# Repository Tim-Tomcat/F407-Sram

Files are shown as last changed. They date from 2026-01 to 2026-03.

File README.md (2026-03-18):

# F407-Sram
## Tổng quan dự án


  - Sơ đồ khối kết nối
  - Mục tiêu thiết kế:
    - Mạch debug STM, yêu cầu thiết lập trở kháng 90 Ohm đối với cổng USB.
    - Mạch USB <-> UART, giao tiếp với STM32.
    - Mạch gắn thẻ SD (sai footprint, không có linh kiện khớp).
    - Kết nối STM32F407ZGT6 với Sram 4Mbit thông qua bus FSMC.
      - Thiết lập trở kháng bus FSMC có giá trị 50 Ohm.
      - Kiểm soát length matching nhỏ nhất có thể (±2mm<).
      - Thêm điện trở nối tiếp để giảm over/undershoot và giảm méo tín hiệu. 
    - Kết nối với IC Ethernet DP83848 thông qua bus RMII (Thất bại).
      - Thiết lập trở kháng cho cổng ETH có giá trị 100 Ohm.
<br/>


Hình: Kiểm soát length matching(±2mm<)



Cách kết nối IC K6R4008V1D:
| Pin Name | Pin Function |
|---|---|
| A0 - A18 | Address Inputs |
| WE | Write Enable |
| CS | Chip Select |
| OE | Output Enable |
| I/O1 ~ I/O8  | Data Inputs/Outputs|

  - Được điều khiển bởi các tín hiệu: CS (Chip Select), WE (Write Enable), OE (Output Enable).
  - I/O1–I/O8 tạo thành bus dữ liệu song song 8 bit, hai chiều (bidirectional), dùng cho cả đọc và ghi SRAM tùy theo trạng thái điều khiển.
  - A0–A18 là các đường địa chỉ (19 bit), cho phép truy cập 2¹⁹ = 524,288 địa chỉ, tương ứng dung lượng 4 Mbit (512 KB).

<br/>




Hình: Mạch thi công thực tế
<br/>



<br/>



<br/>



<br/>



## Thử nghiệm đọc ghi Sram

Hình: FMC memory banks (RM0090, Figure 457)

  - Vùng địa chỉ của FMC được chia thành nhiều bank, trong đó Bank 1 (0x6000_0000 → 0x6FFF_FFFF) hỗ trợ các loại bộ nhớ như NOR, PSRAM và SRAM. Đây là vùng được sử dụng để ánh xạ SRAM ngoài trong thí nghiệm.
  - Sử dụng thư viện HAL, thử bằng phương pháp ghi và đọc lại Sram, nếu phát hiện đọc khác ghi thì lỗi sẽ được ghi nhận
(Vì đây là phương pháp thử cơ bản để kiểm tra kết nối giữa MCU và Sram, khi thực hiện phức tạp hơn thì vẫn có lỗi xảy ra)

<br/>



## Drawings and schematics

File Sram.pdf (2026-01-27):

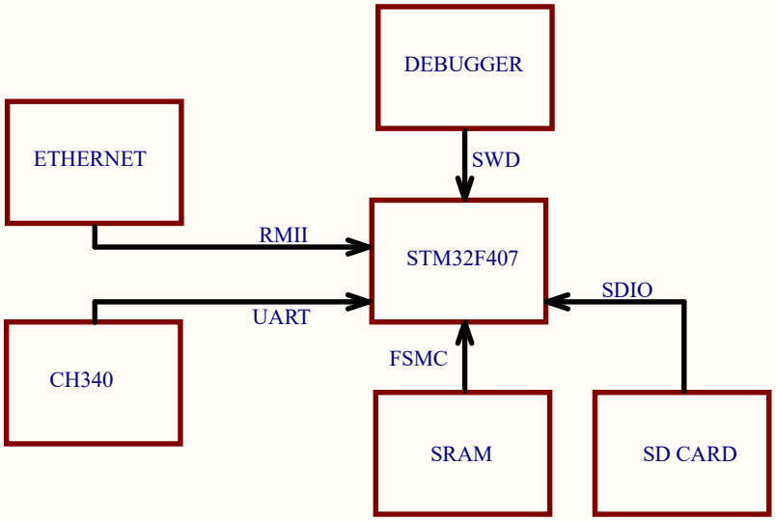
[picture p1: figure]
STM32F407; DEBUGGER; ETHERNET; SWD; RMII; UART; SRAM; SD CARD; FSMC; SDIO

# KHỐI NGUỒN

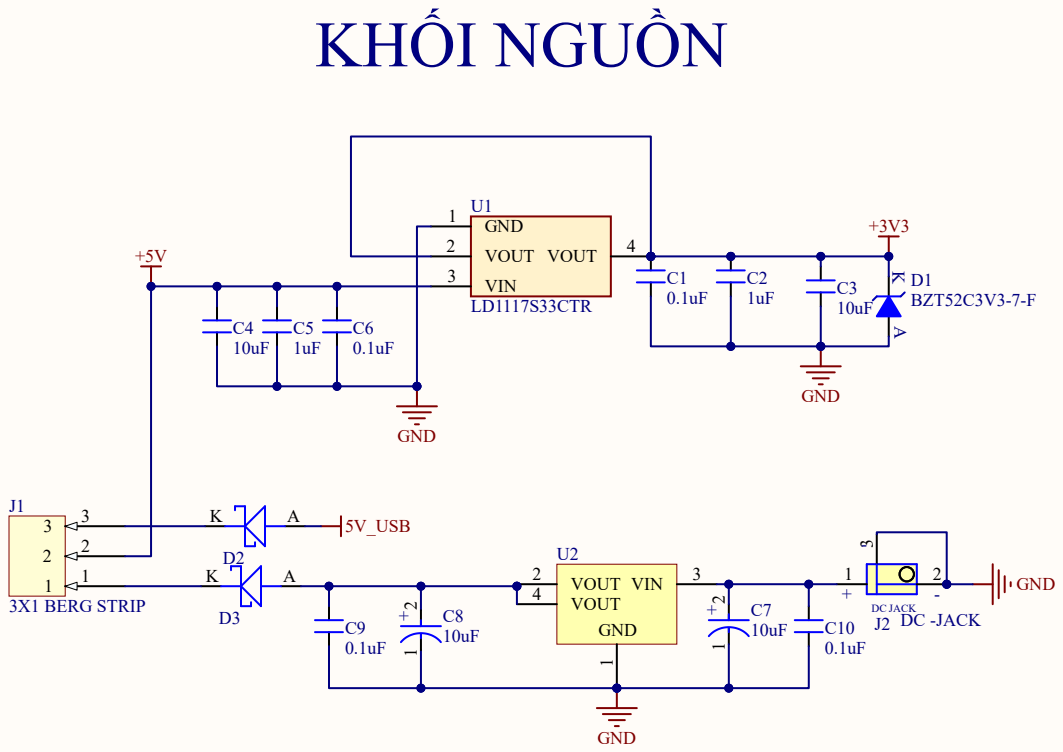
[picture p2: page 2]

# ST-Link V2

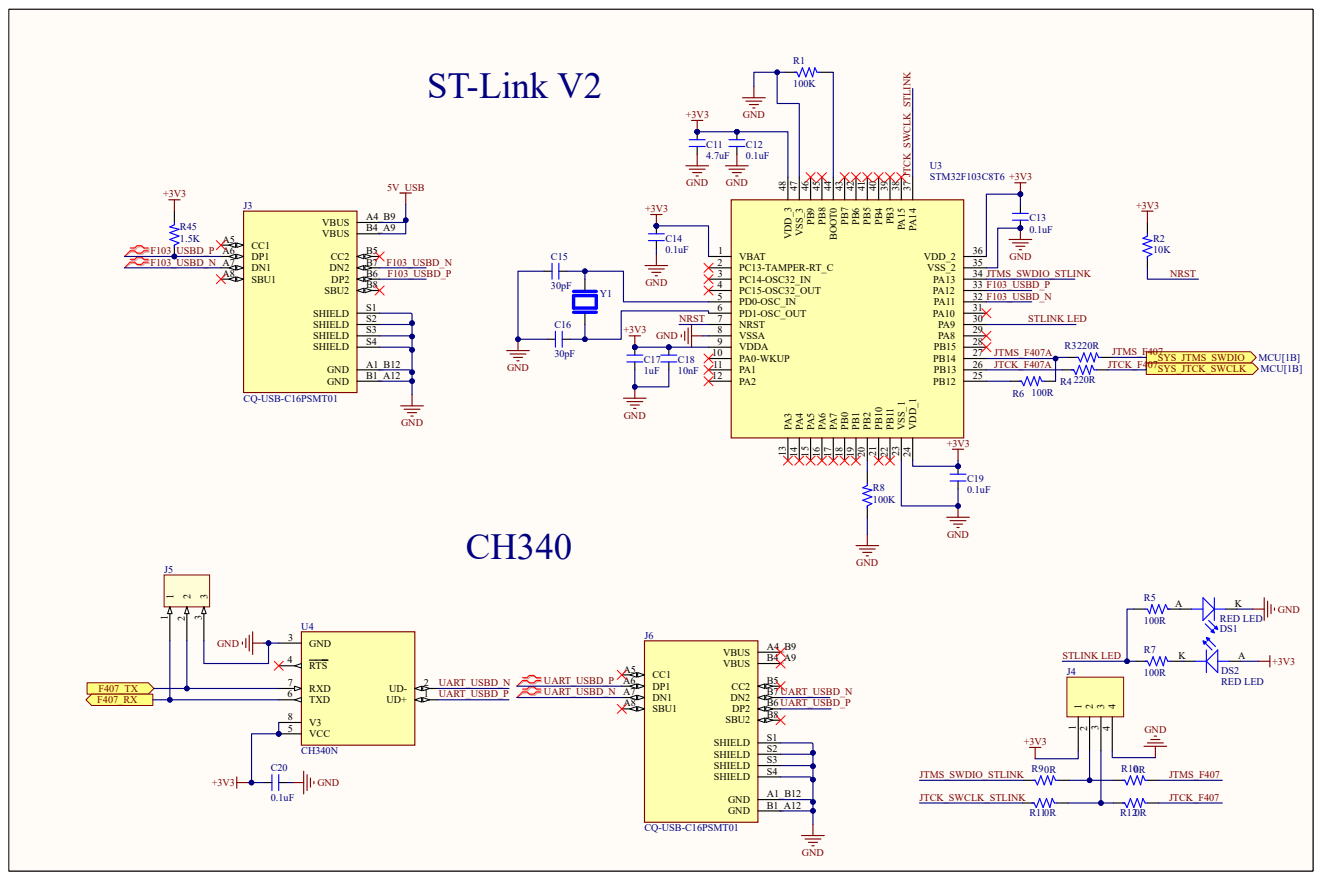
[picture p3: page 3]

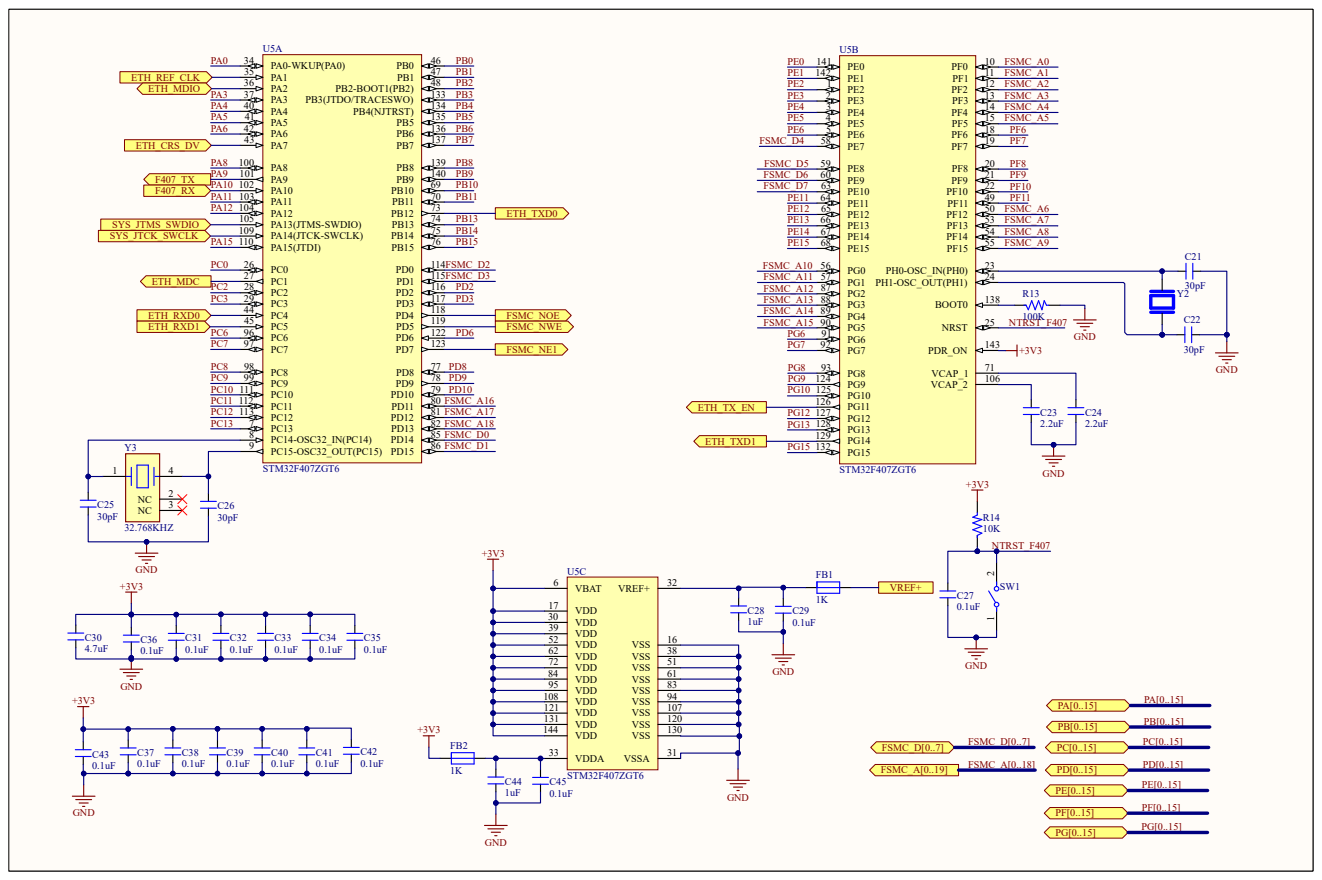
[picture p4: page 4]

DP83848

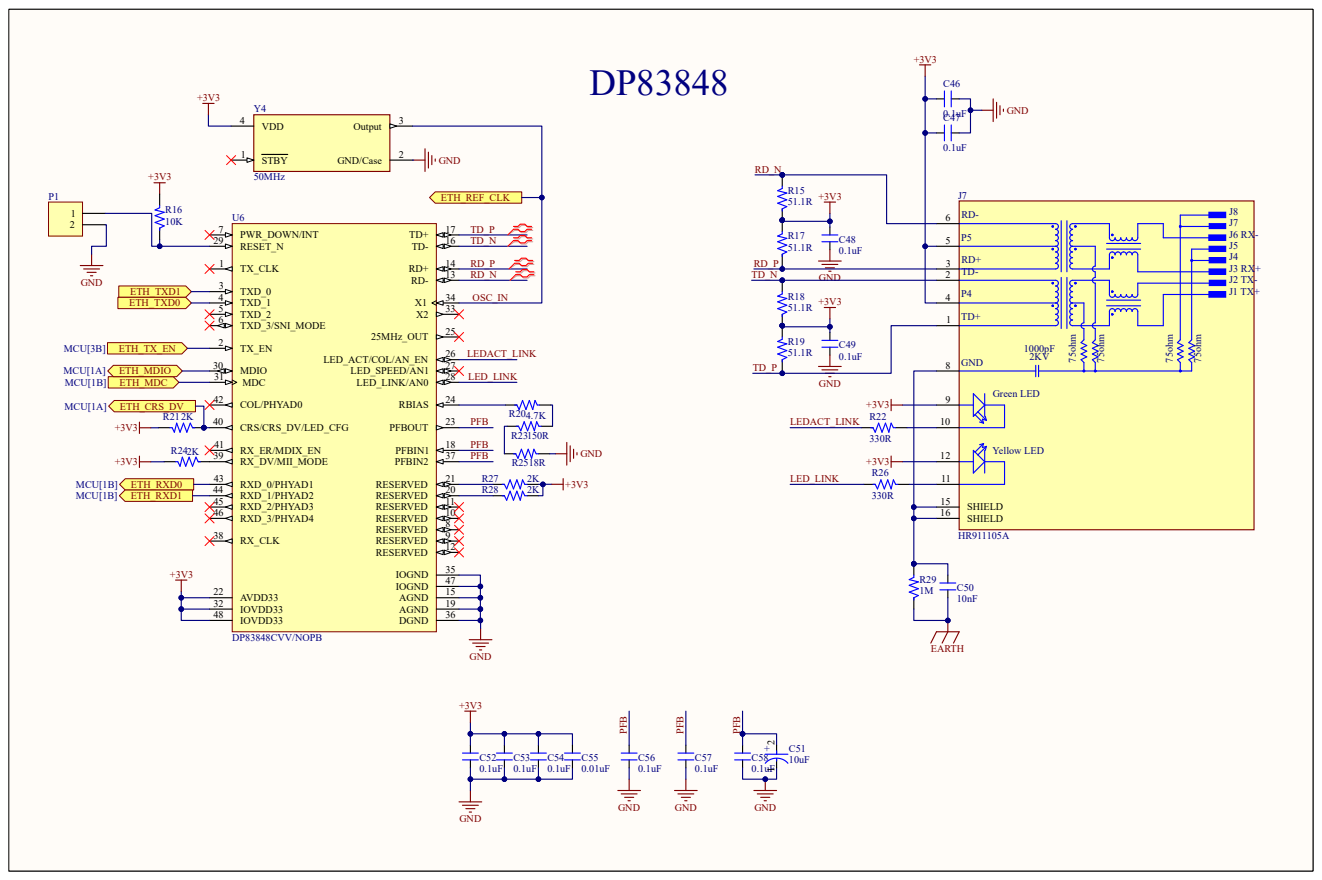
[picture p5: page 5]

+3V3 1 2

+3V3 1 2

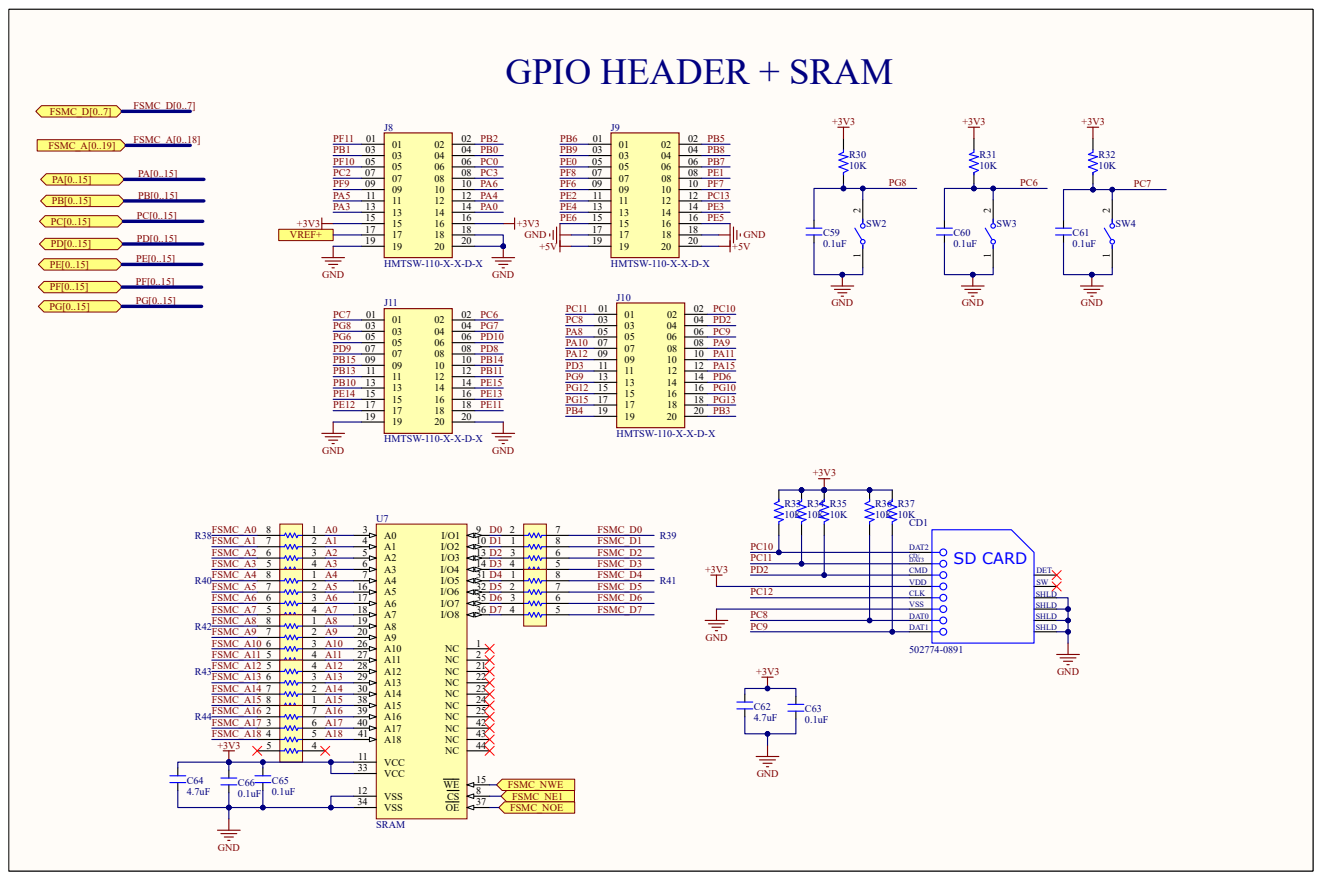
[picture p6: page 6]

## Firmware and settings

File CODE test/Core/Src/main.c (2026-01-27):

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
/* Includes ------------------------------------------------------------------*/
#include "main.h"

/* USER CODE BEGIN Includes */
#include <stdio.h>
#include <string.h>
#include <stdarg.h>
/* USER CODE END Includes */

/* USER CODE BEGIN PD */
#define SRAM_BANK_ADDR ((uint32_t)0x60000000)
#define SRAM_SIZE      0x8000
#define TEST_PATTERN_1 0xEA
/* USER CODE END PD */

UART_HandleTypeDef huart1;

SRAM_HandleTypeDef hsram1;

void SystemClock_Config(void);
static void MX_GPIO_Init(void);
static void MX_FSMC_Init(void);
static void MX_USART1_UART_Init(void);
/* USER CODE BEGIN PFP */
void printmsg(char *format,...);
/* USER CODE END PFP */

/* USER CODE BEGIN 0 */
void test_sram(void) {
    volatile uint8_t *p_sram = (uint8_t *)SRAM_BANK_ADDR;
    uint32_t error_count = 0;
    uint32_t i;

    printmsg("UART1: [SRAM TEST] Bat dau...\r\n");

    // BƯỚC 1: Ghi Pattern vào TOÀN BỘ vùng nhớ
    printmsg("UART1: Dang ghi du lieu (Write All)...\r\n");
    for (i = 0; i < SRAM_SIZE; i++) {
        p_sram[i] = (uint8_t)TEST_PATTERN_1;
    }

    // BƯỚC 2: Đọc lại và so sánh
    for (i = 0; i < SRAM_SIZE; i++) {
        uint8_t data_read = p_sram[i];

        if (data_read != (uint8_t)TEST_PATTERN_1) {
            error_count++;

            if (error_count <= 10) {
                printmsg("Loi tai 0x%08X -> Doc: 0x%02X, Ky vong: 0x%02X\r\n",
                         (unsigned int)(SRAM_BANK_ADDR + i), data_read, TEST_PATTERN_1);
            }
        }
    }

    // BƯỚC 3: Tổng kết
    if (error_count == 0) {
        printmsg("[KET QUA] SRAM PASS. Khong co loi.\r\n");
    } else {
        printmsg("[KET QUA] SRAM FAIL. Tong so loi: %u\r\n", error_count);
        if (error_count > 10) {
            printmsg("UART1: (Da an bot %u loi phia sau)\r\n", error_count - 10);
        }
    }
}

/* USER CODE END 0 */

/**
  * @brief  The application entry point.
  * @retval int
  */
int main(void)
{

  /* MCU Configuration--------------------------------------------------------*/

  /* Reset of all peripherals, Initializes the Flash interface and the Systick. */
  HAL_Init();

  /* Configure the system clock */
  SystemClock_Config();

  /* Initialize all configured peripherals */
  MX_GPIO_Init();
  MX_FSMC_Init();
  MX_USART1_UART_Init();
  /* USER CODE BEGIN 2 */
  test_sram();
  /* USER CODE END 2 */

  /* Infinite loop */
  /* USER CODE BEGIN WHILE */
  while (1)
  {
    /* USER CODE END WHILE */

    /* USER CODE BEGIN 3 */
  }
  /* USER CODE END 3 */
}

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
/* USER CODE BEGIN 4 */
void printmsg(char *format,...)
{
  char str[100];
  va_list args;
  va_start(args, format);
  vsprintf(str, format,args);
  HAL_UART_Transmit(&huart1,(uint8_t *)str, strlen(str),HAL_MAX_DELAY);
  va_end(args);
}
/* USER CODE END 4 */
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


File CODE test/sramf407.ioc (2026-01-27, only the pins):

Mcu.UserName=STM32F407ZGTx
PA10.Signal=USART1_RX
PA13.Signal=SYS_JTMS-SWDIO
PA14.Signal=SYS_JTCK-SWCLK
PA9.Signal=USART1_TX
PC14-OSC32_IN.Signal=RCC_OSC32_IN
PC15-OSC32_OUT.Signal=RCC_OSC32_OUT
PD0.Signal=FSMC_D2_DA2
PD1.Signal=FSMC_D3_DA3
PD11.Signal=FSMC_A16_CLE
PD12.Signal=FSMC_A17_ALE
PD13.Signal=FSMC_A18
PD14.Signal=FSMC_D0_DA0
PD15.Signal=FSMC_D1_DA1
PD4.Signal=FSMC_NOE
PD5.Signal=FSMC_NWE
PD7.Signal=FSMC_NE1
PE10.Signal=FSMC_D7_DA7
PE7.Signal=FSMC_D4_DA4
PE8.Signal=FSMC_D5_DA5
PE9.Signal=FSMC_D6_DA6
PF0.Signal=FSMC_A0
PF1.Signal=FSMC_A1
PF12.Signal=FSMC_A6
PF13.Signal=FSMC_A7
PF14.Signal=FSMC_A8
PF15.Signal=FSMC_A9
PF2.Signal=FSMC_A2
PF3.Signal=FSMC_A3
PF4.Signal=FSMC_A4
PF5.Signal=FSMC_A5
PG0.Signal=FSMC_A10
PG1.Signal=FSMC_A11
PG2.Signal=FSMC_A12
PG3.Signal=FSMC_A13
PG4.Signal=FSMC_A14
PG5.Signal=FSMC_A15

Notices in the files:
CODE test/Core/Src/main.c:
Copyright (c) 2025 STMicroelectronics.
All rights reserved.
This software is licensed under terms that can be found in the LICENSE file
